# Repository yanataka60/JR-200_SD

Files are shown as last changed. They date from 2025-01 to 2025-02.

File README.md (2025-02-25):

# National JR-200にSD-CARDとのロード、セーブ機能

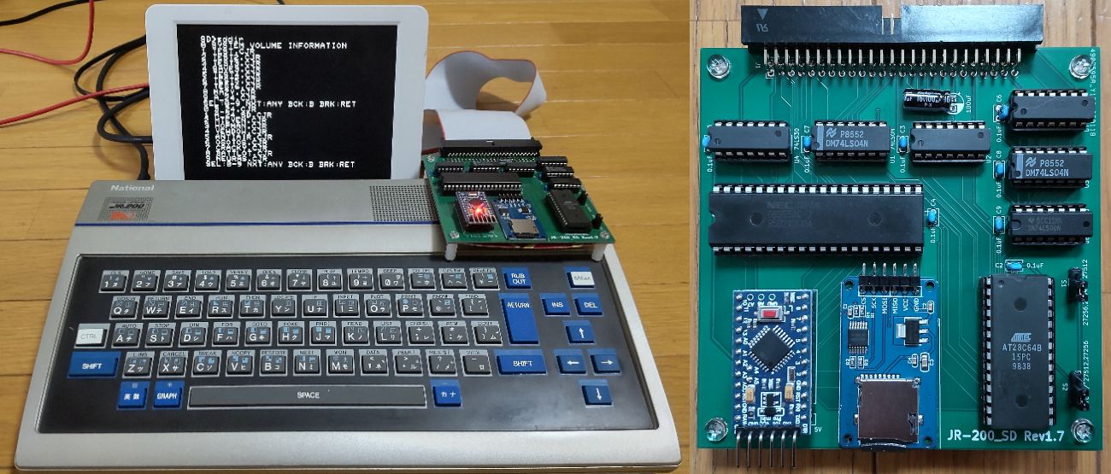
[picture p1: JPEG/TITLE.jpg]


　JR-200でSD-CARDからcjr形式ファイルのロード、セーブ機能を実現するものです。

　CMTからの読み込み実行に数分掛かっていたゲームも数十秒で実行できます。

　接続は、JR-200本体後ろの拡張端子からフラットケーブルで接続して使います。

　なお、Arduino、ROMへ書き込むための機器が別途必要となります。

### 2025.2.26 PIOに6821を使ったRev2.1ではPIOアクセス時の画面ノイズが発生しないので6821版を正式版とし、8255版は8255フォルダに移動しました。なお、開発に使用した2台のJR-200では6821版、8255版ともに安定動作していますが、8255版は動作不安定であると報告された機体でも6821版は安定動作しているとの動作報告がありました。

## 回路図
　KiCadフォルダ内のJR-200_SD.pdfを参照してください。

[回路図](https://github.com/yanataka60/JR-200_SD/blob/main/Kicad/JR-200_SD.pdf)

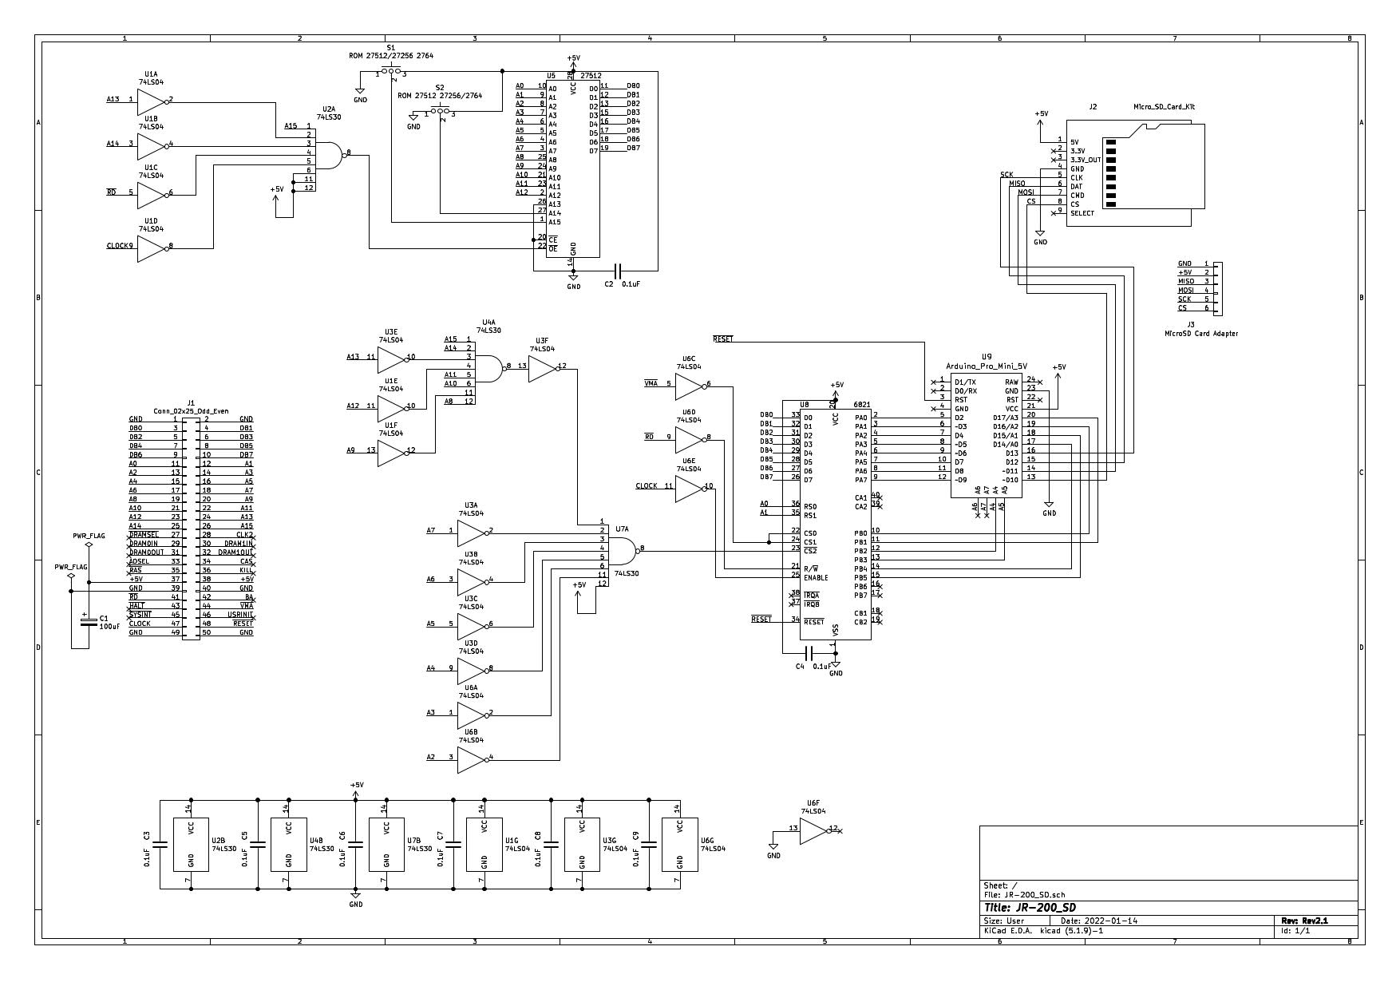
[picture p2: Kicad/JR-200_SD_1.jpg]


## 部品
|番号|品名|数量|備考|
| --- | --- | --- | --- |
|J1|2x25ボックスヘッダ|1|共立エレショップ JS-1200R-50など、秋月電子通商 PH-2x40RGなどのピンヘッダでも代用可(注1)|
||J2、J3のいずれか|||
|J2|Micro_SD_Card_Kit|1|秋月電子通商 AE-microSD-LLCNV (注2) (注3)|
|J3|MicroSD Card Adapter|1|Arduino等に使われる5V電源に対応したもの (注3)|
|S1、S2|3Pスライドスイッチ又はピンヘッダ、ジャンパーピン|2|秋月電子通商 SS12D01G4など|
|U1、U3、U6|74LS04|3||
|U2、U4、U7|74LS30|3||
|U5|ROM 2764/27256/27512相当品|1||
|U8|6821|1|若松通商 HD46821P等|
|U9|Arduino_Pro_Mini_5V|1|Atmega328版を使用 168版は不可。(注4)|
|C2-C9|積層セラミックコンデンサ 0.1uF|8||
|C1|電解コンデンサ 16v100uF|1||
||50Pinフラットケーブル|1||
||ピンヘッダ|2Pin分|Arduino_Pro_MiniにはA4、A5用のピンヘッダが付いていないため別途調達が必要です 秋月電子通商 PH-1x40SGなど|
||ピンソケット(任意)|26Pin分|Arduino_Pro_Miniを取り外し可能としたい場合に調達します 秋月電子通商 FHU-1x42SGなど|

　　　注1)ピンヘッダで代用するときは、基板から若干浮かせてピンヘッダをハンダ付けするとフラットケーブをスムーズに抜き差しできます。

　　　注2)秋月電子通商　AE-microSD-LLCNVのJ1ジャンパはショートしてください。

　　　注3)J2又はJ3のどちらかを選択して取り付けてください。

### 　　注4)Arduino Pro MiniはA4、A5ピンも使っています。

### MicroSD Card Adapterを使う
　J3に取り付けます。

　MicroSD Card Adapterについているピンヘッダを除去してハンダ付けするのが一番確実ですが、J3の穴にMicroSD Card Adapterをぴったりと押しつけ、裏から多めにハンダを流し込むことでハンダ付けをする方法もあります。なお、この方法の時にはしっかりハンダ付けが出来たかテスターで導通を確認しておいた方が安心です。

　ハンダ付けに自信のない方はJ2の秋月電子通商　AE-microSD-LLCNVをお使いください。AE-microSD-LLCNVならパワーLED、アクセスLEDが付いています。

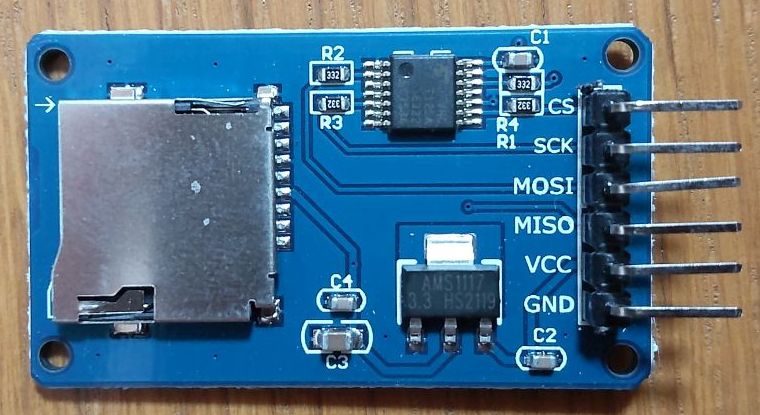
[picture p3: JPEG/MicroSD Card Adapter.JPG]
MicroSD Card Adapter


## ROMへの書込み
　ROMフォルダ内のSD.binをROMライター(TL866II Plus等)を使って2764、27256又は27512に書き込みます。

### ROMの相性
　開発中にAT28C64 15PCを使ったところ、正常に動作しないという現象がありました。

　AT28C64 15PCよりアクセスタイムが遅いROMを使用しても問題が発生しないため、単純にアクセスタイムの早いROMを使えばよいと言う訳でもないようです。

　入手性を鑑み、2764、27256、27512互換ROMを使えるようにしてあります。
#### 問題なし
|メーカー|品名|
| --- | -- |
|ATMEL|AT28C64B-15PC|
|NEC|D27512J-2|
|ST|M2764A-25F1|
|ST|M27256-2F1|
|ST|M27C512-10F1|
|TOSHIBA|TMM2764D|
|TOSHIBA|TMM2764AD-20|
|Winbond|W27C512-45Z|

#### 問題あり
|メーカー|品名|備考|
| --- | -- | -- |
|ATMEL|AT28C64-15PC|ほぼ誤動作|
|ATMEL|AT28C256-15PC|2764とはピン非互換|
|ATMEL|AT29C256-25PC|時々誤動作|

## Arduinoプログラム
　Arduino IDEを使ってArduinoフォルダのJR-200_SDフォルダ内JR-200.inoを書き込みます。

　SdFatライブラリを使用しているのでArduino IDEメニューのライブラリの管理からライブラリマネージャを立ち上げて「SdFat」をインストールしてください。

　「SdFat」で検索すれば見つかります。「SdFat」と「SdFat - Adafruit Fork」が見つかりますが「SdFat」のほうを使っています。

注)Arduinoを基板に直付けしている場合、Arduinoプログラムを書き込むときは、JR-200本体とは接続を外したうえで書き込んでください。

## 接続
　JR-200本体後ろの拡張端子からフラットケーブルで接続します。

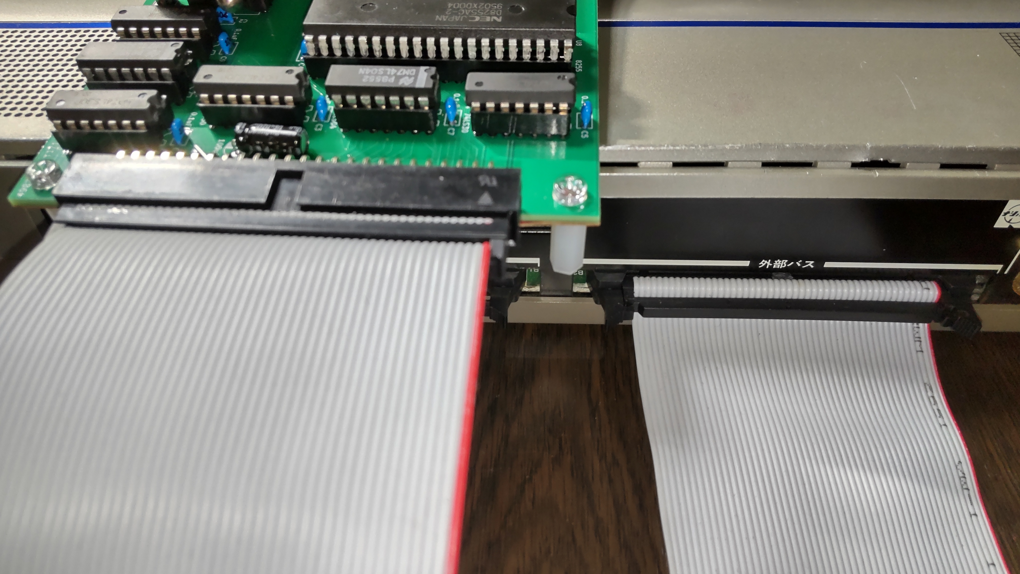
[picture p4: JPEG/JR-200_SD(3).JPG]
JR-200_SD Back


#### 注)JR-200本体上面の塗装の下には伝導性の塗装(?)があるようで剥げかけている個所に接触するとショートの可能性があります。基板を本体上面に置くときには基板下面が本体と接触しないよう絶縁してください。

## SD-CARD
　出来ればSD規格のSDカードを用意してください。

　ArduinoのSdFatライブラリは、SD規格(最大2GB)、SDHC規格(2GB～32GB)に対応していますが、SDXC規格(32GB～2TB)には対応していません。

　また、SDHC規格のSDカードであっても相性により動作しないものがあるようです。

　FAT16又はFAT32が認識できます。NTFSは認識できません。

　ルートに置かれた拡張子が「.CJR」のCJR形式ファイルのみ認識できます。(CJR形式以外のファイル、フォルダも表示されますがLOADの対象になりません)

　ファイル名は「.CJR」を含めて31文字まで、ただし半角カタカナ、及び一部の記号はArduinoが認識しないので使えません。パソコンでファイル名を付けるときはアルファベット、数字および空白でファイル名をつけてください。

## CJR形式
　複数セクションが含まれるCJRファイルは読み込ませないでください。最初のセクションの読込が終了した後、Arduinoは次のセクションを送出しようとして待機状態となり、電源を入れ直すか、RESETするまで正常に動作しなくなります。

## 動作環境
　現在5.00と5.01での動作を確認しています。

## 使い方

### Launcherの起動
　MONコマンドでモニタに入り、G8000[CR]でLauncherが起動します。(Gは大文字)

　注)BASICからa=usr($8000)でも起動出来ますが、BASICプログラムをロードした後は、!コマンドで戻らずにBREAKキーで戻ってください。!コマンドで戻るとBASICプログラムが壊れます。

　コマンドプロンプトが「>」から「SD>」に変わり以下のコマンドが使えるようになります。

　~SDへのアクセス中に画面にノイズが出ますが、異常ではありません。ノイズが出ないようにする方法が不明なためそのままにしてあります。~(2025.2.20 PIOを6821にすることで解消されました。)

#### SDDIR[CR]又はSDDIR "文字列"[CR]
　SDDIR[CR]とするとSD-CARDルートディレクトリにあるファイルの一覧を表示します。

　SDDIR "文字列"[CR]とするとSD-CARDルートディレクトリにあるその文字列から始まるファイルの一覧を表示します。ダブルコーテーションはあっても無くても構いません。

　10件表示したところで指示待ちになるので打ち切るならRETURNを入力すると打ち切られ、Bキーで前の10件に戻ります。それ以外のキーで次の10件を表示します。

　LOADしたいファイルを見つけたら左端の数字のキーを押せばLOADされます。

　BASICプログラムか、機械語プログラムかは自動で判断します。

　表示される順番は、登録順となりファイル名アルファベッド順などのソートした順で表示することはできません。

#### LOAD "DOSファイル名"[CR]
　指定したDOSフィル名のプログラムをSD-CARDからLOADします。ダブルコーテーションはあっても無くても構いません。

　BASICプログラムか、機械語プログラムかは自動で判断し、どちらをLOADしているかメッセージに表示します。

　また、機械語プログラムのLOAD時には読み込み開始アドレス、読み込み終了アドレスも表示されます。

　ファイル名の最後の「.CJR」は有っても無くても構いません。

　例)

　　LOAD "TEST" -> DOSファイル名「TEST.CJR」を読み込みます。

　　LOAD "TEST.BAS" -> DOSファイル名「TEST.BAS.CJR」を読み込みます。

　　LOAD "TEST.BAS.CMT" -> DOSファイル名「TEST.BAS.CJR」を読み込みます。

#### MEXEC[CR]
　機械語プログラムをLOADした後、Gxxxx[CR]として機械語プログラムを実行する代わりに実行アドレスが読み込み開始アドレスと同じ場合にはMEXEC[CR]とすることで機械語プログラムを実行できます。

#### SAVE "DOSファイル名"[CR]
　BASICプログラムを指定したDOSフィル名でSD-CARDに上書きSAVEします。ダブルコーテーションはあっても無くても構いません。

　ファイル名の省略は出来ません。

　ファイル名の最後の「.CJR」は有っても無くても構いません。

　指定したDOSファイル名の最初の16文字がCJR形式の中に保存されるファイル名として使われます。

　BASICプログラムであることを識別するためDOSファイル名に「.BAS」を含ませることを推奨します。

　例)

　　SAVE "TEST" -> 「TEST.CJR」で保存される。

　　SAVE "TEST.BAS" -> 「TEST.BAS.CJR」で保存される。

#### MSAVE $xxxx,$yyyy,"DOSファイル名"[CR]
　16進数4桁で指定する$xxxxから$yyyyまでの機械語プログラムを指定したDOSフィル名でSD-CARDに上書きSAVEします。ダブルコーテーションはあっても無くても構いません。

　16進数4桁で指定するアドレスは$をつけてもつけなくても構いません。

　ファイル名の省略は出来ません。

　ファイル名の最後の「.CJR」は有っても無くても構いません。

　指定したDOSファイル名の最初の16文字がCJR形式の中に保存されるファイル名として使われます。

　機械語プログラムであることを識別するためDOSファイル名に「.BIN」を含ませることを推奨します。

　例)

　　MSAVE $E000,$FFFF,"TEST" -> 「TEST.CJR」で保存される。

　　MSAVE E000,FFFF,"TEST.BIN" -> 「TEST.BIN.CJR」で保存される。

#### G $xxxx[CR]
　16進数4桁で指定する$xxxxから始まるプログラムを実行します。

　16進数4桁で指定するアドレスは$をつけてもつけなくても構いません。

#### ![CR]
　JR-200のMONITORに戻ります。

　BASICからa=usr($8000)でLauncherを起動してBASICプログラムをロードした場合には、!コマンドでBASICに戻らないでください。BASICプログラムが破壊されます。

#### BREAKキー
　BASICに戻ります。

　JR-200のBREAKキーは割込み処理によりどんな時でもBASICに戻れるのですが、SDDIRを実行して10件表示したところで指示待ちの時には絶対に押さないでください。

　Arduinoが指示待ちのままになり、電源を再投入するか、リセットするまでSDは使えなくなります。

### BASICプログラム中から機械語プログラムをSDからLOADしたい場合
#### A=USR($8003):REM xxxxx
　A=USR($8003)の直後に書かれたREM文のコメント文字列(xxxxx)をファイル名として解釈してSDからLOADします。

　文字列をダブルコーテーションで括っても括らなくても構いません。また、事前にLauncherの起動も不要です。

　ただし、LOADするのは機械語プログラムのみにしてください。

　BASICプログラムをLOADするとBASICに復帰した時にBASICプログラムを破壊してしまい暴走します。(ダイレクトモードであっても破壊されます)

　例)

　　10 A=USR($8003):REM Demodata

## 操作上の注意
　SD-CARDにアクセスしていない時には電源が入ったままでもSD-CARDを抜くことが出来ます。

　再度SD-CARDを挿入した後、SDDIR、LOAD、SAVE等でSD-CARDに3回ほどアクセスすれば復旧します。

　ただし、SD-CARDの抜き差しは電源を切った状態で行うほうがより確実です。

## 謝辞
　基板の作成に当たり以下のデータを使わせていただきました。ありがとうございました。

　　Arduino Pro Mini

　　　https://github.com/g200kg/kicad-lib-arduino

　　AE-microSD-LLCNV

　　　https://github.com/kuninet/PC-8001-SD-8kRAM

## 追記
2025.1.27 部品に50Pinフラットケーブルを追加しました。

2025.1.29 コネクタの記述を修正しました。

2025.1.31 MSAVEのアドレス指定に$がついていた誤記を訂正しました。

2025.1.31 MSAVEのアドレス指定に$をつけてもつけなくてもよいことに修正。Gコマンドの記述が抜けていたので追加。JR-200_SD設置時の注意を追記。

2025.2.3 動作が不安定な時があるとの動作報告があったことを追記。

2025.2.20 PIOに6821を採用した6821版に移行した。

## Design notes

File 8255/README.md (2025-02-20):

# JR-200_SD 8255版

PIOに8255を使ったVersionではPIOアクセス時にノイズが発生しますが異常ではありません。

PIOに6821を使ったVersionを正式Versionとしますが、入手性の良さから8255Versionも残しておきます。

開発に使用した2台のJR-200では安定動作していますが、動作が不安定な時があるとの報告もあります。

#### 2025.2.3追記　動作が不安定な時があると報告がありました。電源の電流不足かもという話も出ていますが、開発に使用した2台のJR-200では安定動作しています。原因は今のところ不明ですが、本体の個体差により動作が安定しない可能性もあります。

## 回路図
　8255フォルダ、KiCadフォルダ内のJR-200_SD.pdfを参照してください。

[回路図](https://github.com/yanataka60/JR-200_SD/blob/main/8255/Kicad/JR-200_SD.pdf)

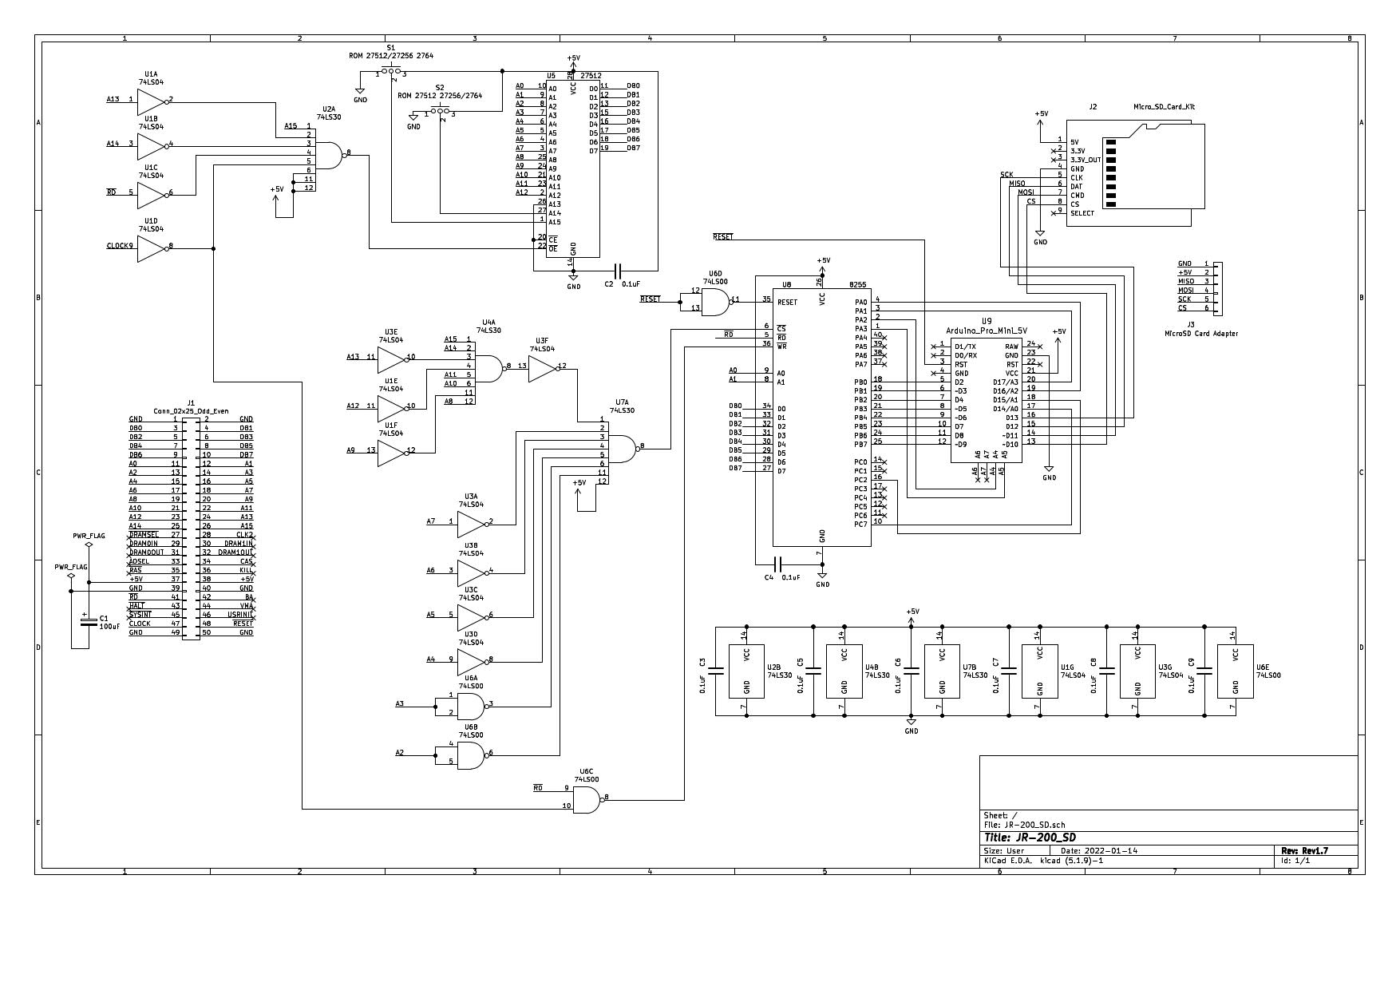
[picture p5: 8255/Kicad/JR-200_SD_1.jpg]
JR-200_SD


## 部品
　6821版との違いは、U6がLS04ではなくLS00であること、U8が6821ではなく8255であることです。

|番号|品名|数量|備考|
| --- | --- | --- | --- |
|J1|2x25ボックスヘッダ|1|共立エレショップ JS-1200R-50など、秋月電子通商 PH-2x40RGなどのピンヘッダでも代用可(注1)|
||J2、J3のいずれか|||
|J2|Micro_SD_Card_Kit|1|秋月電子通商 AE-microSD-LLCNV (注2) (注3)|
|J3|MicroSD Card Adapter|1|Arduino等に使われる5V電源に対応したもの (注3)|
|S1、S2|3Pスライドスイッチ又はピンヘッダ、ジャンパーピン|2|秋月電子通商 SS12D01G4など|
|U1、U3|74LS04|2||
|U2、U4、U7|74LS30|3||
|U5|ROM 2764/27256/27512相当品|1||
|U6|74LS00|1||
|U8|8255|1||
|U9|Arduino_Pro_Mini_5V|1|Atmega328版を使用 168版は不可。(注4)|
|C2-C9|積層セラミックコンデンサ 0.1uF|8||
|C1|電解コンデンサ 16v100uF|1||
||50Pinフラットケーブル|1||
||ピンヘッダ|2Pin分|Arduino_Pro_MiniにはA4、A5用のピンヘッダが付いていないため別途調達が必要です 秋月電子通商 PH-1x40SGなど|
||ピンソケット(任意)|26Pin分|Arduino_Pro_Miniを取り外し可能としたい場合に調達します 秋月電子通商 FHU-1x42SGなど|

　　　注1)ピンヘッダで代用するときは、基板から若干浮かせてピンヘッダをハンダ付けするとフラットケーブをスムーズに抜き差しできます。

　　　注2)秋月電子通商　AE-microSD-LLCNVのJ1ジャンパはショートしてください。

　　　注3)J2又はJ3のどちらかを選択して取り付けてください。

### 　　注4)Arduino Pro MiniはA4、A5ピンも使っています。

### MicroSD Card Adapterを使う
　J3に取り付けます。

　MicroSD Card Adapterについているピンヘッダを除去してハンダ付けするのが一番確実ですが、J3の穴にMicroSD Card Adapterをぴったりと押しつけ、裏から多めにハンダを流し込むことでハンダ付けをする方法もあります。なお、この方法の時にはしっかりハンダ付けが出来たかテスターで導通を確認しておいた方が安心です。

　ハンダ付けに自信のない方はJ2の秋月電子通商　AE-microSD-LLCNVをお使いください。AE-microSD-LLCNVならパワーLED、アクセスLEDが付いています。

MicroSD Card Adapter

## ROMへの書込み
　8255フォルダ、ROMフォルダ内のSD.binをROMライター(TL866II Plus等)を使って2764、27256又は27512に書き込みます。

## 以下は6821Versionと同様です。

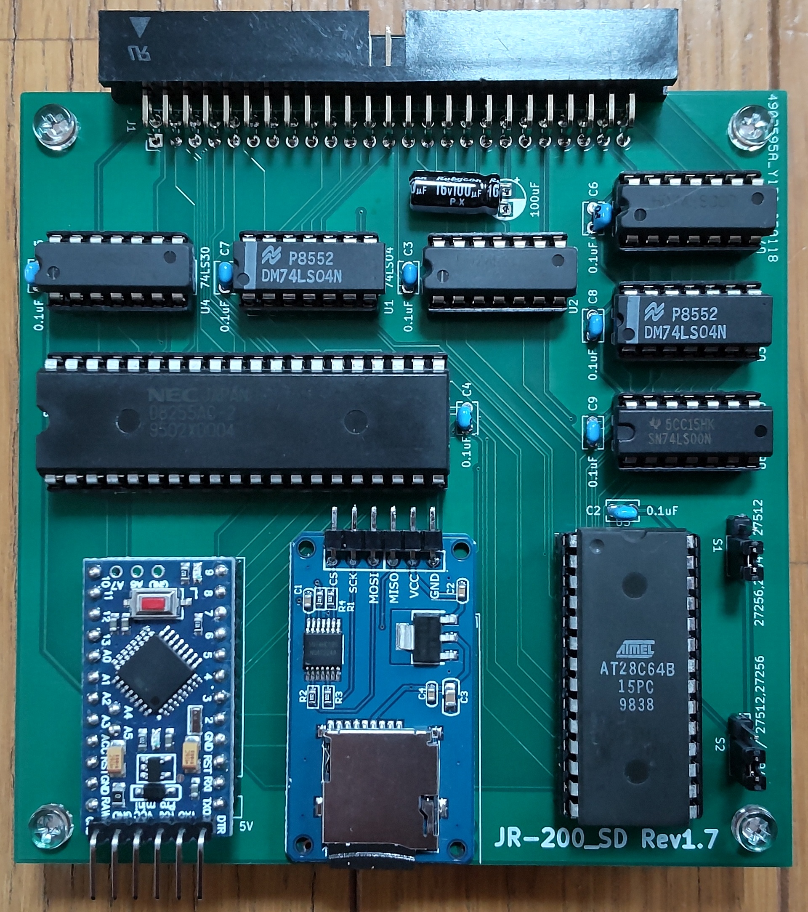
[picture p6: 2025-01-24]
JPEG/JR-200_SD(2).JPG

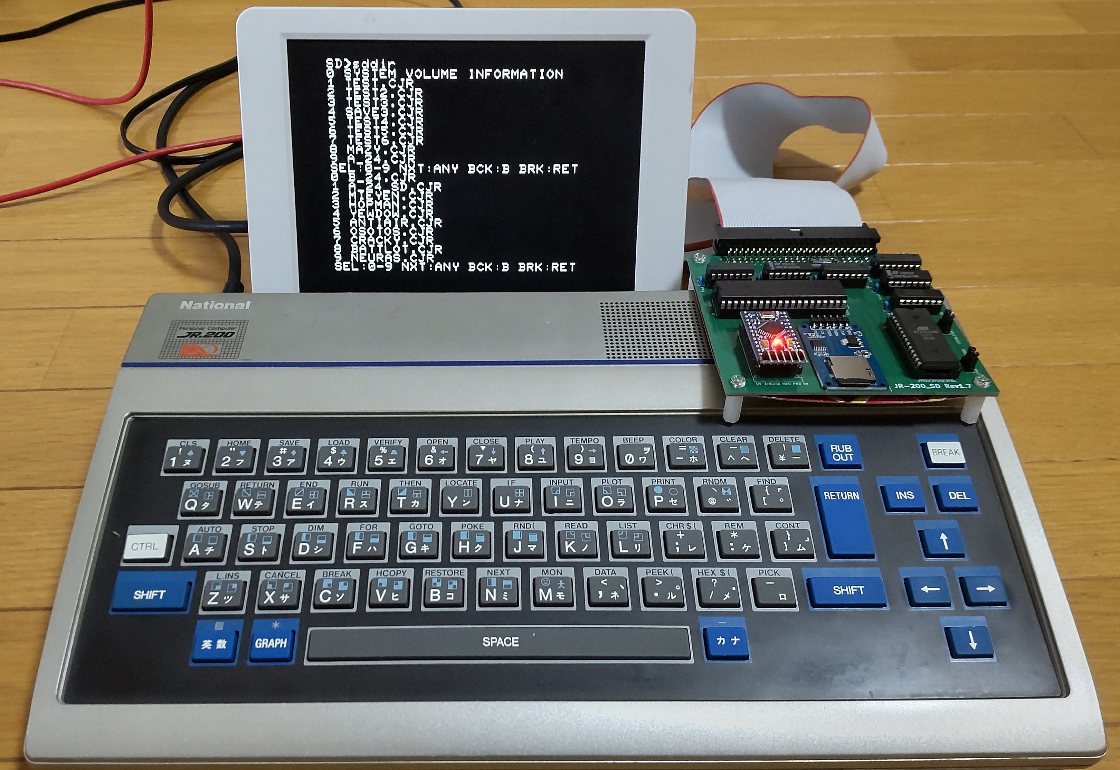
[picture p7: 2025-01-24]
JPEG/JR-200_SD(1).JPG

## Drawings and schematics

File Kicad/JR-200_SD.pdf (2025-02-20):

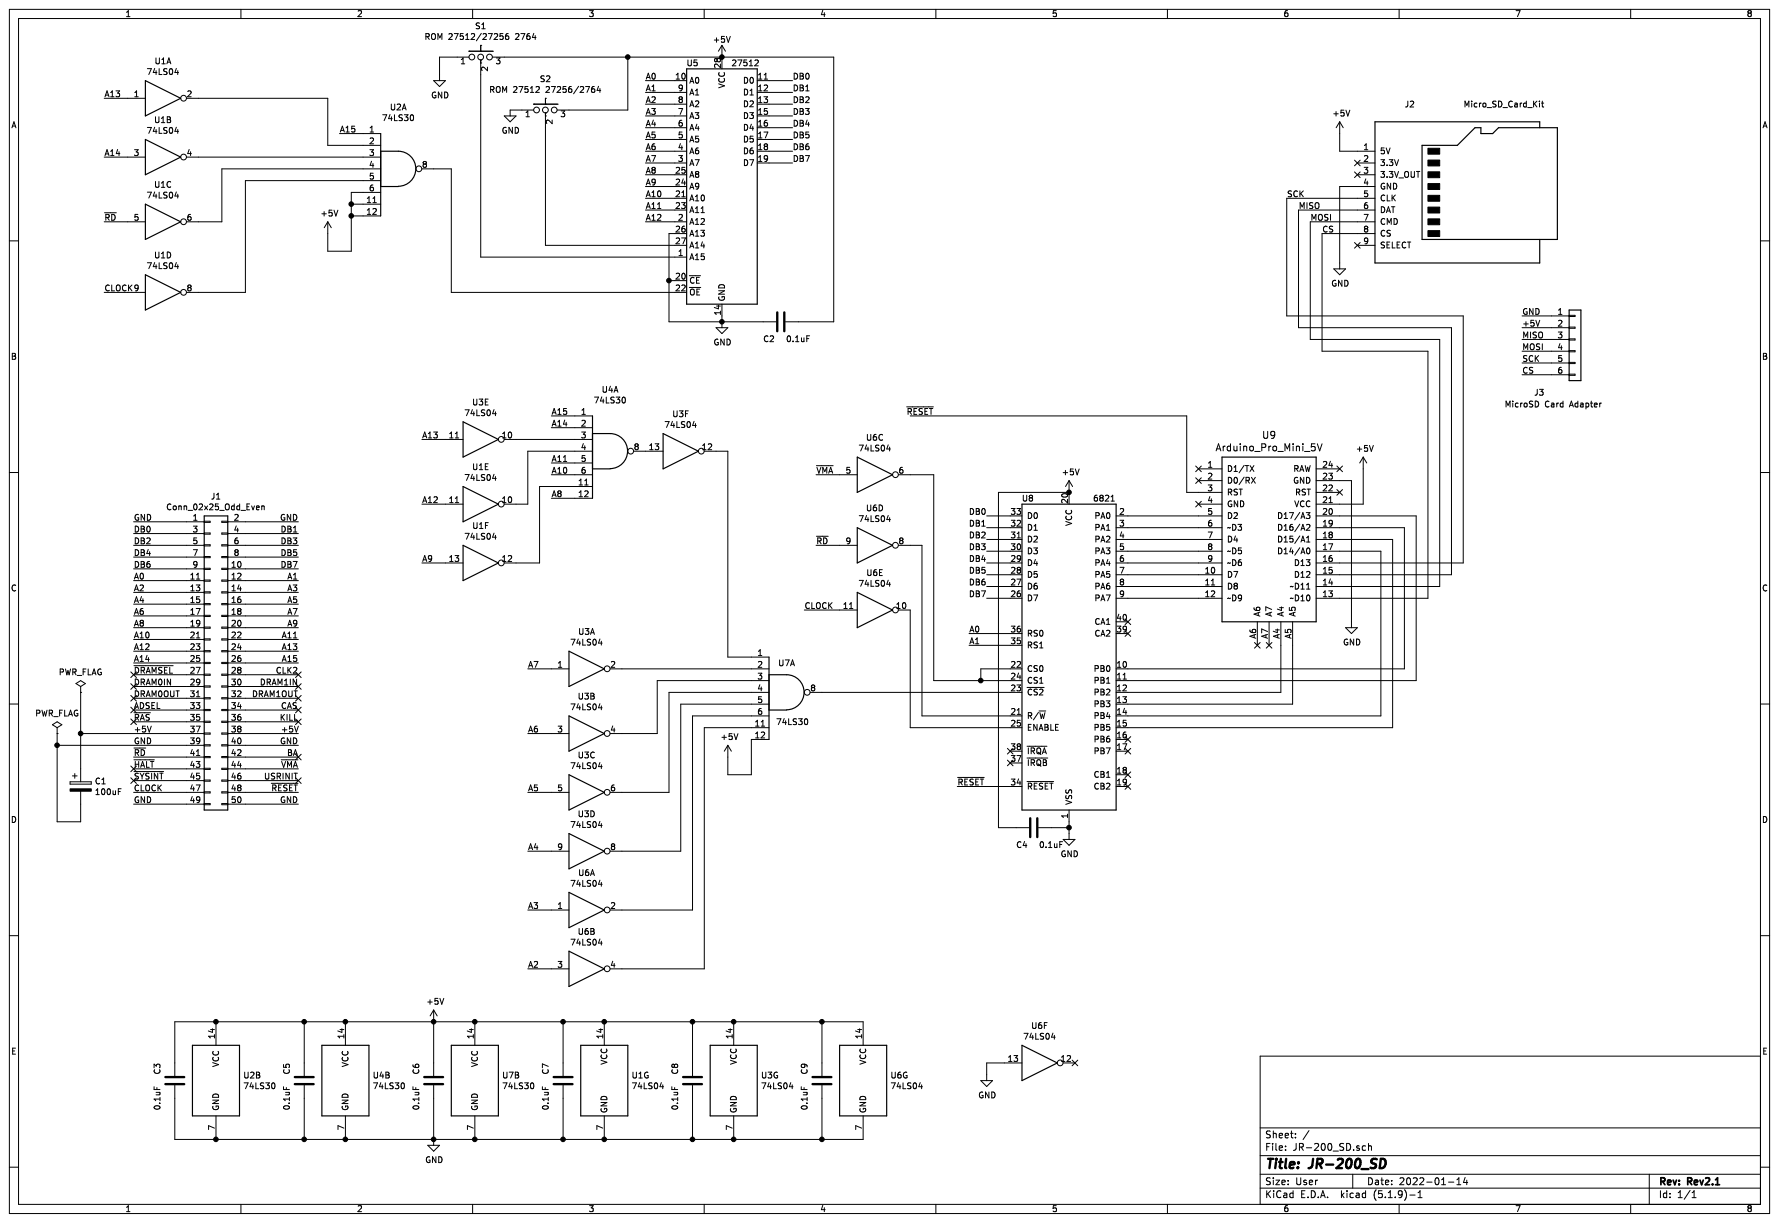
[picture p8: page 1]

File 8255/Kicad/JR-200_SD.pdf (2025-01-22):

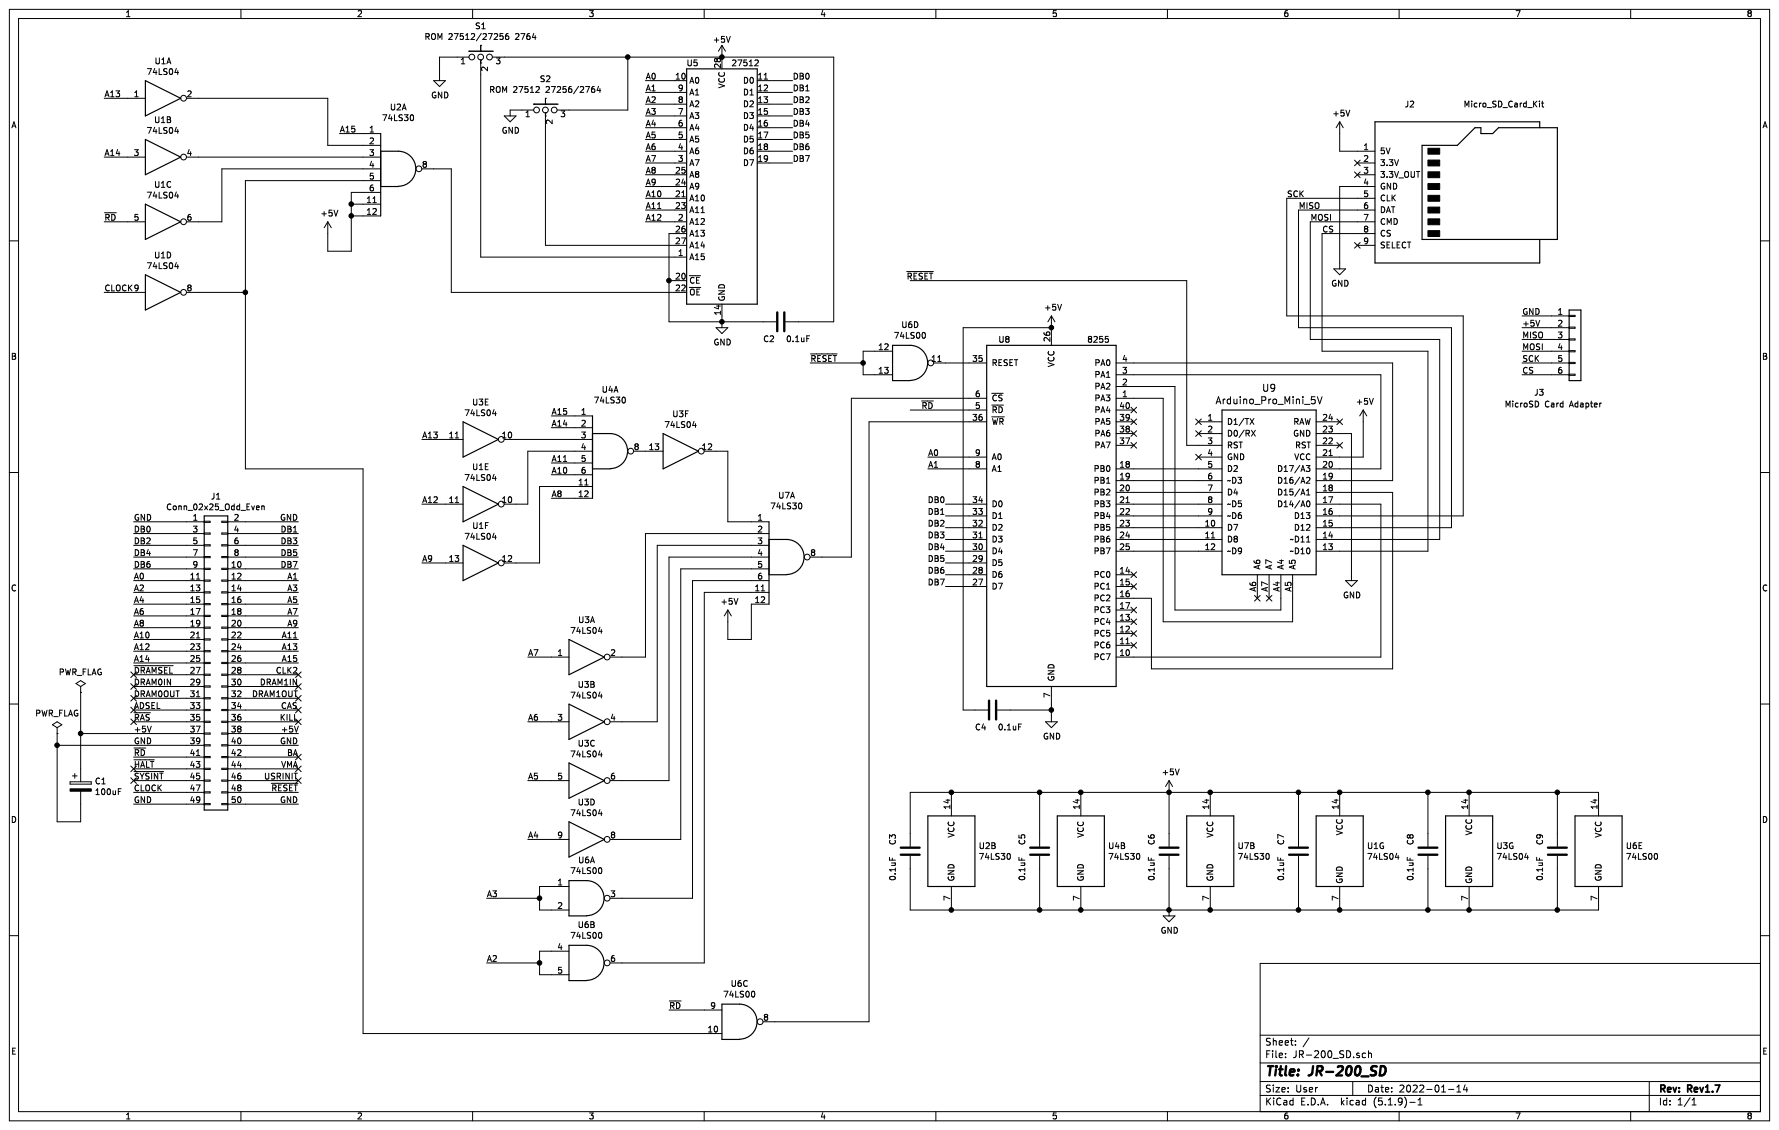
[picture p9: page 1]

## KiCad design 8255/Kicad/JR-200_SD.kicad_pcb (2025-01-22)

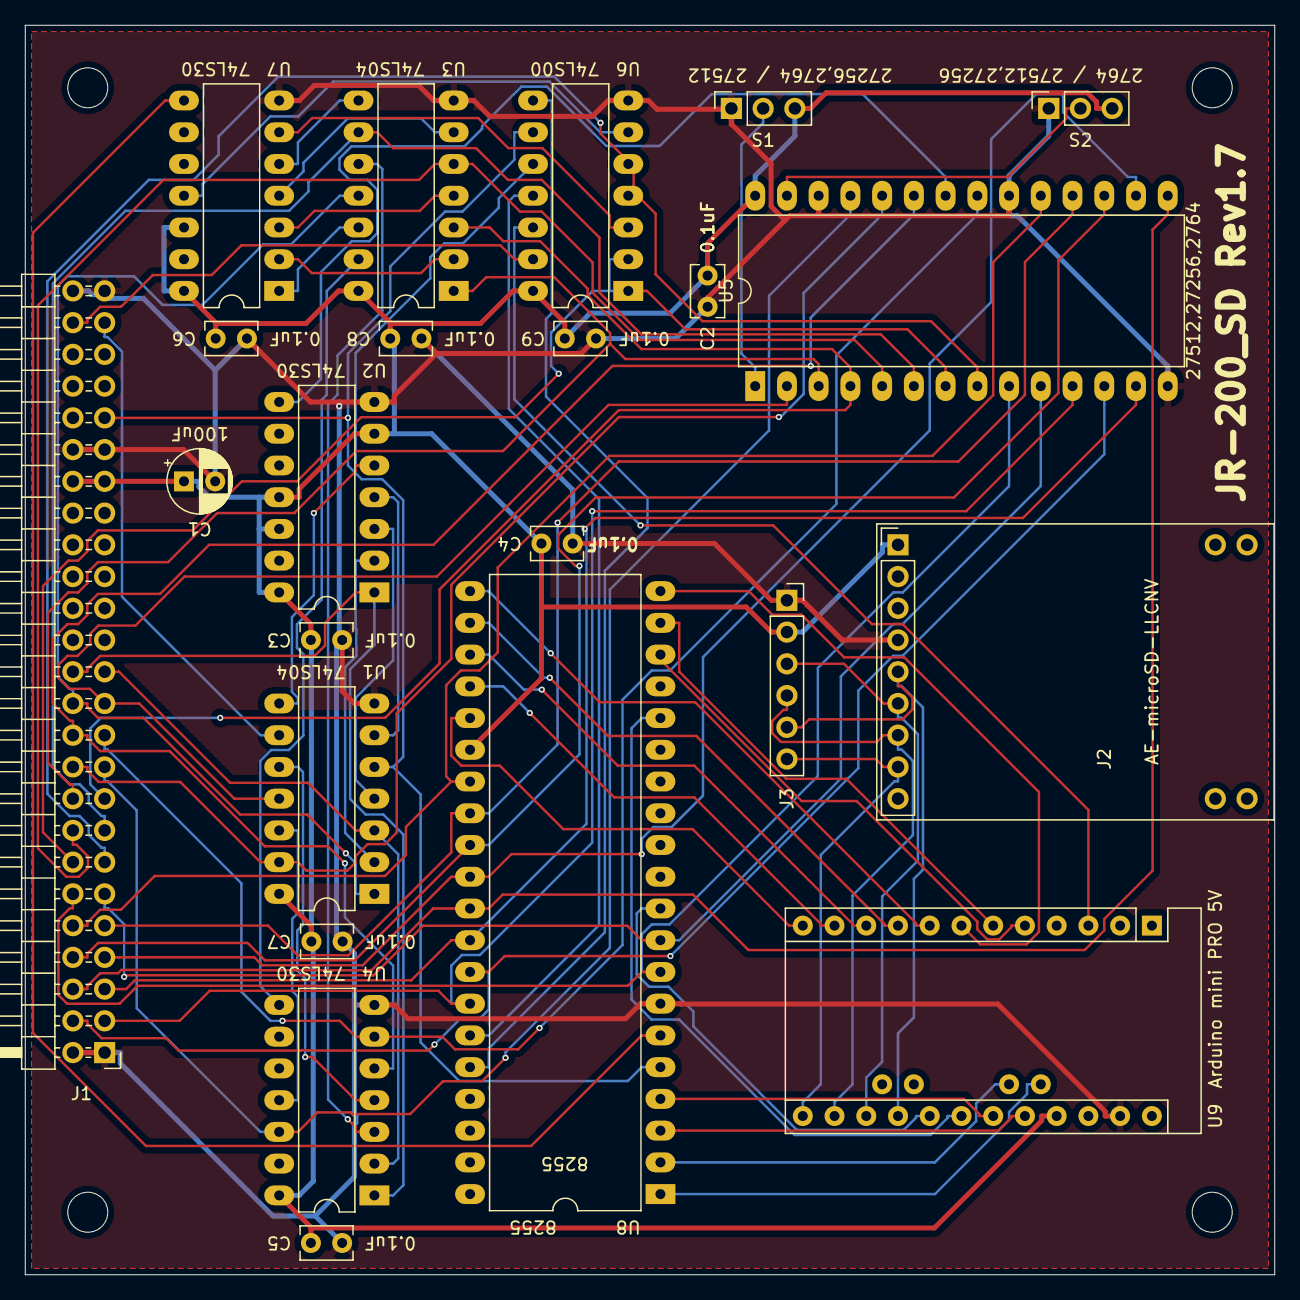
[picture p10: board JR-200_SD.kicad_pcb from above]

Board: 2 copper layers, 100.0 x 100.0 mm, 27 parts (0 on the bottom side), 68 nets.

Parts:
C1: 100uF; CP_Radial_D5.0mm_P2.50mm
C2, C3, C4, C5, C6, C7, C8, C9: 0.1uF; C_Rect_L4.0mm_W2.5mm_P2.50mm
J1: Conn_02x25_Odd_Even; PinHeader_2x25_P2.54mm_Horizontal
J2: Micro_SD_Card_Kit; AE-microSD-LLCNV
J3: MicroSD Card Adapter; PinSocket_1x06_P2.54mm_Vertical
MH1, MH2, MH3, MH4: MountingHole_3.2mm_M3
S1: ROM 27512/27256 2764; PinSocket_1x03_P2.54mm_Vertical
S2: ROM 27512 27256/2764; PinSocket_1x03_P2.54mm_Vertical
U1, U3: 74LS04; DIP-14_W7.62mm_LongPads
U2, U4, U7: 74LS30; DIP-14_W7.62mm_LongPads
U5: 27512; DIP-28_W15.24mm_LongPads
U6: 74LS00; DIP-14_W7.62mm_LongPads
U8: 8255; DIP-40_W15.24mm_LongPads
U9: Arduino_Pro_Mini_5V; Arduino_Pro_Mini

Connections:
+5V: C1.1, C2.2, C3.1, C4.1, C5.1, C6.1, C7.1, C8.1, C9.1, J1.37, J1.38, J2.1, J3.2, S1.3, S2.3, U1.14, U2.6, U2.11, U2.12, U2.14, U3.14, U4.14, U5.28, U6.14, U7.12, U7.14, U8.26, U9.21
/A0: J1.11, U5.10, U8.9
/A1: J1.12, U5.9, U8.8
/A2: J1.13, U5.8, U6.4, U6.5
/A3: J1.14, U5.7, U6.1, U6.2
/A4: J1.15, U3.9, U5.6
/A5: J1.16, U3.5, U5.5
/A6: J1.17, U3.3, U5.4
/A7: J1.18, U3.1, U5.3
/A8: J1.19, U4.12, U5.25
/A9: J1.20, U1.13, U5.24
/A10: J1.21, U4.6, U5.21
/A11: J1.22, U4.5, U5.23
/A12: J1.23, U1.11, U5.2
/A13: J1.24, U1.1, U3.11
/A14: J1.25, U1.3, U4.2
/A15: J1.26, U2.1, U4.1
/CLOCK: J1.47, U1.9
/CS: J2.8, J3.6, U9.13
/DB0: J1.3, U5.11, U8.34
/DB1: J1.4, U5.12, U8.33
/DB2: J1.5, U5.13, U8.32
/DB3: J1.6, U5.15, U8.31
/DB4: J1.7, U5.16, U8.30
/DB5: J1.8, U5.17, U8.29
/DB6: J1.9, U5.18, U8.28
/DB7: J1.10, U5.19, U8.27
/MISO: J2.6, J3.3, U9.15
/MOSI: J2.7, J3.4, U9.14
/SCK: J2.5, J3.5, U9.16
/~RD: J1.41, U1.5, U6.9, U8.5
/~RESET: J1.48, U6.12, U6.13, U9.3
GND: C1.2, C2.1, C3.2, C4.2, C5.2, C6.2, C7.2, C8.2, C9.2, J1.1, J1.2, J1.39, J1.40, J1.49, J1.50, J2.4, J3.1, S1.1, S2.1, U1.7, U2.7, U3.7, U4.7, U5.14, U5.20, U5.26, U6.7, U7.7, U8.7, U9.23
unnamed: S1.2, U5.1
unnamed: S2.2, U5.27
unnamed: U1.2, U2.2
unnamed: U1.4, U2.3
unnamed: U1.6, U2.4
unnamed: U1.8, U2.5, U6.10
unnamed: U1.10, U4.4
unnamed: U1.12, U4.11
unnamed: U2.8, U5.22
unnamed: U3.2, U7.2
unnamed: U3.4, U7.3
unnamed: U3.6, U7.4
unnamed: U3.8, U7.5
unnamed: U3.10, U4.3
unnamed: U3.12, U7.1
unnamed: U3.13, U4.8
unnamed: U6.3, U7.6
unnamed: U6.6, U7.11
unnamed: U6.8, U8.36
unnamed: U6.11, U8.35
unnamed: U7.8, U8.6
unnamed: U8.1, U9.A5
unnamed: U8.2, U9.A4
unnamed: U8.3, U9.20
unnamed: U8.4, U9.19
unnamed: U8.10, U9.17
unnamed: U8.16, U9.18
unnamed: U8.18, U9.5
unnamed: U8.19, U9.6
unnamed: U8.20, U9.7
unnamed: U8.21, U9.8
unnamed: U8.22, U9.9
unnamed: U8.23, U9.10
unnamed: U8.24, U9.11
unnamed: U8.25, U9.12

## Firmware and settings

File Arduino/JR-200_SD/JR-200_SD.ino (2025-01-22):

#include "SdFat.h"
#include <SPI.h>
SdFat SD;
char m_name[40];
char f_name[40];
char c_name[40];
char buf1[10],buf2[10];
char sdir[10][40];
File file;
byte f_length2,f_length1;
unsigned int f_length;
#define CABLESELECTPIN  (10)
#define CHKPIN          (15)
#define PB0PIN          (2)
#define PB1PIN          (3)
#define PB2PIN          (4)
#define PB3PIN          (5)
#define PB4PIN          (6)
#define PB5PIN          (7)
#define PB6PIN          (8)
#define PB7PIN          (9)
#define FLGPIN          (14)
#define PA0PIN          (16)
#define PA1PIN          (17)
#define PA2PIN          (18)
#define PA3PIN          (19)
// ファイル名は、ロングファイルネーム形式対応
boolean eflg;

void sdinit(void){
  // SD初期化
  if( !SD.begin(CABLESELECTPIN,8) )
  {
////    Serial.println("Failed : SD.begin");
    eflg = true;
  } else {
////    Serial.println("OK : SD.begin");
    eflg = false;
  }
////    Serial.println("START");
}

void setup(){
////  Serial.begin(9600);
// CS=pin10
// pin10 output

  pinMode(CABLESELECTPIN,OUTPUT);
  pinMode( CHKPIN,INPUT);  //CHK
  pinMode( PB0PIN,OUTPUT); //送信データ
  pinMode( PB1PIN,OUTPUT); //送信データ
  pinMode( PB2PIN,OUTPUT); //送信データ
  pinMode( PB3PIN,OUTPUT); //送信データ
  pinMode( PB4PIN,OUTPUT); //送信データ
  pinMode( PB5PIN,OUTPUT); //送信データ
  pinMode( PB6PIN,OUTPUT); //送信データ
  pinMode( PB7PIN,OUTPUT); //送信データ
  pinMode( FLGPIN,OUTPUT); //FLG

  pinMode( PA0PIN,INPUT_PULLUP); //受信データ
  pinMode( PA1PIN,INPUT_PULLUP); //受信データ
  pinMode( PA2PIN,INPUT_PULLUP); //受信データ
  pinMode( PA3PIN,INPUT_PULLUP); //受信データ

  digitalWrite(PB0PIN,LOW);
  digitalWrite(PB1PIN,LOW);
  digitalWrite(PB2PIN,LOW);
  digitalWrite(PB3PIN,LOW);
  digitalWrite(PB4PIN,LOW);
  digitalWrite(PB5PIN,LOW);
  digitalWrite(PB6PIN,LOW);
  digitalWrite(PB7PIN,LOW);
  digitalWrite(FLGPIN,LOW);

  sdinit();
}

//4BIT受信
byte rcv4bit(void){
//HIGHになるまでループ
  while(digitalRead(CHKPIN) != HIGH){
  }
//受信
  byte j_data = digitalRead(PA0PIN)+digitalRead(PA1PIN)*2+digitalRead(PA2PIN)*4+digitalRead(PA3PIN)*8;
//FLGをセット
  digitalWrite(FLGPIN,HIGH);
//LOWになるまでループ
  while(digitalRead(CHKPIN) == HIGH){
  }
//FLGをリセット
  digitalWrite(FLGPIN,LOW);
  return(j_data);
}

//1BYTE受信
byte rcv1byte(void){
  byte i_data = 0;
  i_data=rcv4bit()*16;
  i_data=i_data+rcv4bit();
  return(i_data);
}

//1BYTE送信
void snd1byte(byte i_data){
//下位ビットから8ビット分をセット
  digitalWrite(PB0PIN,(i_data)&0x01);
  digitalWrite(PB1PIN,(i_data>>1)&0x01);
  digitalWrite(PB2PIN,(i_data>>2)&0x01);
  digitalWrite(PB3PIN,(i_data>>3)&0x01);
  digitalWrite(PB4PIN,(i_data>>4)&0x01);
  digitalWrite(PB5PIN,(i_data>>5)&0x01);
  digitalWrite(PB6PIN,(i_data>>6)&0x01);
  digitalWrite(PB7PIN,(i_data>>7)&0x01);
  digitalWrite(FLGPIN,HIGH);
//HIGHになるまでループ
  while(digitalRead(CHKPIN) != HIGH){
  }
  digitalWrite(FLGPIN,LOW);
//LOWになるまでループ
  while(digitalRead(CHKPIN) == HIGH){
  }
}

//ファイル名の最後が「.cjr」でなければ付加
void addcrj(char *f_name,char *m_name){
  unsigned int lp1=0;
  while (f_name[lp1] != 0x00){
    m_name[lp1] = f_name[lp1];
    lp1++;
  }
  if (f_name[lp1-4]!='.' ||
    ( f_name[lp1-3]!='C' &&
      f_name[lp1-3]!='c' ) ||
    ( f_name[lp1-2]!='J' &&
      f_name[lp1-2]!='j' ) ||
    ( f_name[lp1-1]!='R' &&
      f_name[lp1-1]!='r' ) ){
         m_name[lp1++] = '.';
         m_name[lp1++] = 'c';
         m_name[lp1++] = 'j';
         m_name[lp1++] = 'r';
  }
  m_name[lp1] = 0x00;
}

//SDカードから読込
void f_load(void){
  int wk1 = 0;
  unsigned int lp1;
//ファイルネーム取得
  receive_name(m_name);
    addcrj(m_name,f_name);
//ファイルが存在しなければERROR
  if (SD.exists(f_name) == true){
//ファイルオープン
    file = SD.open( f_name, FILE_READ );
    if( true == file ){
//状態コード送信(OK)
        snd1byte(0x00);

//ファイルサイズ取得
        f_length = file.size();

//データ送信
          if(f_length>0){
            for (lp1 = 1;lp1 <= f_length;lp1++){
              wk1 = file.read();
              snd1byte(wk1);
            }
          }
        file.close();
        sdinit();
     } else {
//状態コード送信(ERROR)
      snd1byte(0xFF);
      sdinit();
     }
   } else {
//状態コード送信(FILE NOT FIND ERROR)
    snd1byte(0xF1);
    sdinit();
  }
}

//SDカードに書き込み
void f_save(void){
  unsigned int lp1;
  byte wk1,wk2,s_adrs1,s_adrs2,sum,blkno;
  unsigned long s_adrs;
  boolean flg;
//ファイルネーム取得
  receive_name(m_name);
    addcrj(m_name,f_name);
////  Serial.println(f_name);
//
//ファイルが存在すればdelete
  if (SD.exists(f_name) == true){
    SD.remove(f_name);
  }
//ファイルオープン
  file = SD.open( f_name, FILE_WRITE );
  if( true == file ){
//状態コード送信(OK)
    snd1byte(0x00);
    if(rcv1byte()==0x00){
//ヘッダブロック
      file.write(0x02);
      file.write(0x2a);
      wk1 = 0x00;
      file.write(wk1);
      file.write(0x1a);
      file.write(0xff);
      file.write(0xff);
      sum = 0x3C;
      flg=false;
      for (lp1 = 0;lp1 <= 15;lp1++){
        wk2 = m_name[lp1];
        if (wk2 == 0){
          flg=true;
        }
        if (flg == true){
          wk2=0;
        }
        sum = sum +wk2;
        file.write(wk2);
      }
      wk1 = rcv1byte();
      file.write(wk1);
      wk1 = 0x00;
      file.write(wk1);
      file.write(0xff);
      file.write(0xff);
      file.write(0xff);
      file.write(0xff);
      file.write(0xff);
      file.write(0xff);
      file.write(0xff);
      file.write(0xff);
      file.write(sum);
//SAVE開始アドレス受信      
      s_adrs1 = rcv1byte();
      s_adrs2 = rcv1byte();
      s_adrs = s_adrs1*256+s_adrs2;
//SAVEデータサイズ受信
      f_length1 = rcv1byte();
      f_length2 = rcv1byte();
      f_length = f_length1*256+f_length2;
//256Byteデータブロック       
      blkno=1;
      while(f_length1 != 0x00){
        file.write(0x02);
        file.write(0x2a);
        sum = 0x02+0x2a;
        file.write(blkno);
        sum = sum + blkno;
        wk1 = 0x00;
        file.write(wk1);
        file.write(s_adrs1);
        file.write(s_adrs2);
        sum = sum + s_adrs1 + s_adrs2;
        for (lp1=1; lp1<=256; lp1++){
          wk1 = rcv1byte();
          file.write(wk1);
          sum = sum + wk1;
        }
        file.write(sum);
        s_adrs1++;
        f_length1--;
        blkno++;
      }
//f_length2 Byteデータブロック
      if(f_length2 != 0){
        file.write(0x02);
        file.write(0x2a);
        sum = 0x02+0x2a;
        file.write(blkno);
        sum = sum + blkno;
        file.write(f_length2);
        sum = sum + f_length2;
        file.write(s_adrs1);
        file.write(s_adrs2);
        sum = sum + s_adrs1 + s_adrs2;
        for (lp1=1; lp1<=f_length2; lp1++){
          wk1 = rcv1byte();
          file.write(wk1);
          sum = sum + wk1;
        }
        file.write(sum);
      }
//フッタブロック
      file.write(0x02);
      file.write(0x2a);
      file.write(0xff);
      file.write(0xff);
      s_adrs=s_adrs+f_length;
      s_adrs1 = s_adrs / 256;
      s_adrs2 = s_adrs % 256;
      file.write(s_adrs1);
      file.write(s_adrs2);
    }
    file.close();
  } else {
//状態コード送信(ERROR)
    snd1byte(0xF1);
    sdinit();
  }
}

//比較文字列取得 32+1文字まで取得、ただしダブルコーテーションは無視する
void receive_name(char *f_name){
char r_data;
  unsigned int lp2 = 0;
  for (unsigned int lp1 = 0;lp1 <= 32;lp1++){
    r_data = rcv1byte();
    if (r_data != 0x22){
      f_name[lp2] = r_data;
      lp2++;
    }
  }
}

//f_nameとc_nameをc_nameに0x00が出るまで比較
//FILENAME COMPARE
boolean f_match(char *f_name,char *c_name){
  boolean flg1 = true;
  unsigned int lp1 = 0;
  while (lp1 <=32 && c_name[0] != 0x00 && flg1 == true){
    if (upper(f_name[lp1]) != upper(c_name[lp1])){
      flg1 = false;
    }
    lp1++;
    if (c_name[lp1]==0x00){
      break;
    }
  }
  return flg1;
}

//小文字->大文字
char upper(char c){
  if('a' <= c && c <= 'z'){
    c = c - ('a' - 'A');
  }
  return c;
}


// SD-CARDのFILELIST
void dirlist(void){
//比較文字列取得 32+1文字まで
  receive_name(c_name);
  File file2 = SD.open( "/" );
  if( file2 == true ){
//状態コード送信(OK)
    snd1byte(0x00);

    File entry =  file2.openNextFile();
    int cntl2 = 0;
    unsigned int br_chk =0;
    int page = 1;
//全件出力の場合には10件出力したところで一時停止、キー入力により継続、打ち切りを選択
    while (br_chk == 0) {
      if(entry){
        entry.getName(f_name,36);
        unsigned int lp1=0;
//一件送信
//比較文字列でファイルネームを先頭から比較して一致するものだけを出力
        if (f_match(f_name,c_name)){
//sdir[]にf_nameを保存
          strcpy(sdir[cntl2],f_name);
          snd1byte(0x30+cntl2);
          snd1byte(0x20);
          while (lp1<=36 && f_name[lp1]!=0x00){
            snd1byte(f_name[lp1]);
            lp1++;
          }
          snd1byte(0x00);
          cntl2++;
        }
      }
// CNTL2 > 表示件数-1
      if (!entry || cntl2 > 9){
//継続・打ち切り選択指示要求
        snd1byte(0xfe);

//選択指示受信(0:継続 B:前ページ 以外:打ち切り)
        br_chk = rcv1byte();
//前ページ処理
        if (br_chk==0x42){
//先頭ファイルへ
          file2.rewindDirectory();
//entry値更新
          entry =  file2.openNextFile();
//もう一度先頭ファイルへ
          file2.rewindDirectory();
          if(page <= 2){
//現在ページが1ページ又は2ページなら1ページ目に戻る処理
            page = 0;
          } else {
//現在ページが3ページ以降なら前々ページまでのファイルを読み飛ばす
            page = page -2;
            cntl2=0;
//page*表示件数
            while(cntl2 < page*10){
                entry =  file2.openNextFile();
                if (f_match(f_name,c_name)){
                  cntl2++;
                }
            }
         }
          br_chk=0;
        }
//1～0までの数字キーが押されたらsdir[]から該当するファイル名を送信
        if(br_chk>=0x30 && br_chk<=0x39){
          file = SD.open( sdir[br_chk-0x30], FILE_READ );
          if( file == true ){
            unsigned int lp2=0;
            snd1byte(0xFD);
            while (lp2<=36 && sdir[br_chk-0x30][lp2]!=0x00){
              snd1byte(sdir[br_chk-0x30][lp2]);
              lp2++;
            }
            snd1byte(0x00);
            file.close();
          }
        }
        page++;
        cntl2 = 0;
      }
//ファイルがまだあるなら次読み込み、なければ打ち切り指示
      if (entry){
        entry =  file2.openNextFile();
      }else{
        br_chk=1;
      }
    }
//処理終了指示
    snd1byte(0xFF);
    snd1byte(0x00);
  }else{
    snd1byte(0xf1);
  }
}

void loop()
{
  digitalWrite(PB2PIN,LOW);
  digitalWrite(PB3PIN,LOW);
  digitalWrite(FLGPIN,LOW);
//コマンド取得待ち
////  Serial.print("cmd:");
  byte cmd = rcv1byte();
////  Serial.println(cmd,HEX);
  if (eflg == false){
    switch(cmd) {
//83hでSDカードからLoad
      case 0x83:
//状態コード送信(OK)
////  Serial.println("LOAD START");
//状態コード送信(OK)
        snd1byte(0x00);
        f_load();
        break;
//84hでSDカードにsave
      case 0x84:
//状態コード送信(OK)
////  Serial.println("SAVE START");
//状態コード送信(OK)
        snd1byte(0x00);
        f_save();
        break;
//82hでSDカードファイル一覧
      case 0x82:
//状態コード送信(OK)
////  Serial.println("SD DIR START");
//状態コード送信(OK)
        snd1byte(0x00);
        sdinit();
        dirlist();
        break;
      default:
//状態コード送信(CMD ERROR)
        snd1byte(0xF4);
    }
  } else {
//状態コード送信(ERROR)
    snd1byte(0xF0);
    sdinit();
  }
}
